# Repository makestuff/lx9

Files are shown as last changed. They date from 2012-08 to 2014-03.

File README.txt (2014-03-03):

COPYRIGHT & DISCLAIMER
----------------------

Copyright (C) 2014 MakeStuff (http://makestuff.eu)

This documentation describes Open Hardware and is licensed under the CERN Open
Hardware Licence v1.2. You may redistribute and modify this documentation under
the terms of the CERN OHL v1.2 (http://ohwr.org/cernohl). This documentation is
distributed WITHOUT ANY EXPRESS OR IMPLIED WARRANTY, INCLUDING OF
MERCHANTABILITY, SATISFACTORY QUALITY AND FITNESS FOR A PARTICULAR PURPOSE.
Please see the CERN OHL v1.2 for applicable conditions.

MAKESTUFF LX9 BOARD REV3
------------------------

Features:
   * 80mm x 80mm, 4-layer PCB (KiCad format).
   * Xilinx Spartan-6 LX9 FPGA[1].
   * Uses FPGALink[2] for programming & host communication.
   * Cypress FX2LP Hi-Speed USB interface (~45 MByte/s).
   * 46 FPGA I/Os on top edge-connector, well-grounded.
   * SPI-bus and 8 FX2LP I/Os on bottom edge-connector.
   * 16 MBytes of SDRAM.
   * SD-card slot.
   * 4 Mbit config flash (~40% free for application data).
   * Flexible power options.

It is intended to be small enough and cheap enough to be used as a building-
block for larger FPGA-based projects, and to be solderable at home with the bare
minimum of tools (i.e no reflow oven, just a decent soldering iron). The
component cost for a small (e.g 10-off) run comes to about $40 for each board,
including the PCB.

The design files are in KiCad format (http://www.kicad-pcb.org). I used this:

http://iut-tice.ujf-grenoble.fr/cao/old_versions/kicad-2012-01-19-BZR3256-stable-UBUNTU_10.10_full_with_components_doc.tgz

...running on x86_64 Ubuntu 12.04.

[1]http://www.xilinx.com/products/silicon-devices/fpga/spartan-6/lx.htm
[2]http://www.makestuff.eu/wordpress/software/fpgalink

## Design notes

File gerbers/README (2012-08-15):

The board is 80mm square, four layers of 1oz copper on FR4 TG130, regular green
soldermask on top & bottom, silkscreen on top & bottom, non-RoHS HASL surface.

There are four NPTH drills: two on CONN1 & two on CONN3; the rest are PTH.

PCB outline:
  lx9-PCB_Edges.gbr

Drills:
  lx9.drl (plated holes)
  lx9-NPTH.drl (non-plated holes)

Top layer:
  lx9-Front.gtl (copper)
  lx9-Mask_Front.gts (soldermask)
  lx9-SilkS_Front.gto (silkscreen)

Ground layer (nearest the top):
  lx9-GND.gbr

+3.3V layer (nearest the bottom):
  lx9-3.3V.gbr

Bottom layer:
  lx9-Back.gbl (copper)
  lx9-Mask_Back.gbs (soldermask)
  lx9-SilkS_Back.gbo (silkscreen)

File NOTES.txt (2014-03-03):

BILL OF MATERIALS
-----------------

Qty  Mfg        Part                   Site     Notes  Suggested Source
1    Xilinx     XC6SLX9-2TQG144C       U1       [1]
1    Cypress    CY7C68013A-56PVXC      U2       [2]
1    Micron     MT48LC8M16A2P-7E       U3       [3]
1    Microchip  24LC128-I/SN           U4              http://uk.rs-online.com/web/p/eeprom-memory-chips/6879089
1    Micron     M25P40-VMN6            U5              http://uk.rs-online.com/web/p/flash-memory-chips/7824597
1    HLWCONN    HW-SD-001-02           CONN1           http://www.ebay.com/itm/180794795415 [SU]
1    -          2x40-pin 2mm header    CONN2    [4]    http://www.ebay.com/itm/170648544414
1    -          Female Mini-B USB skt  CONN3           http://www.ebay.com/itm/251126968870
1    -          2x18-pin 2mm header    CONN4    [5]    http://www.ebay.com/itm/170842982073
1    -          24MHz HC-49/US XTAL    XTAL1           http://www.ebay.com/itm/261078491239
3    -          2.54mm 2-pin jumper    J1-3     [6]    http://www.ebay.com/itm/170902513437
1    -          2.54mm 3-pin jumper    J4       [6]                       "
5    -          22uF EIA3528 tant      C6,9-12  [7]    http://www.ebay.com/itm/160306954443
2    -          22pF 0805 capacitors   C13-14          http://www.ebay.com/itm/251019275826
25   -          470nF 0805 capacitors  *        [8]    http://www.ebay.com/itm/251025068518
4    -          10K 0805 resistors     R1-4,10
3    -          2.2K 0805 resistors    R5-6,9   [9]
1    -          0805 resistor          R11      [10]
2    -          0805 resistor          R7-8     [11]
1    -          0805 capacitor         C30      [11]
1    -          AMS1117 SOT-223 3.3V   REG3.3          http://www.ebay.com/itm/170845847551
1    -          AMS1117 SOT-223 1.2V   REG1.2          http://www.ebay.com/itm/170966438741

NOTES
-----

[1] You can also use an LX4 FPGA: XC6SLX4-2TQG144C

[2] A CY7C68014A-56PVXC will also work, as will the 8KiB CY7C68013-56PVXC, but
    it's not recommended; I can't guarantee the firmware will stay inside the
    8KiB limit forever.

[3] Any 64Mbit or 128Mbit SDRAM with the same organization/pinout will suffice.
    For example: Micron MT48LC8M16A2P-6A or MT48LC8M16A2P-7E,
                 Samsung K4S281632F-TC(L)-60 or K4S281632F-TC(L)-75
                 Alliance AS4C8M16S-6TCN or AS4C8M16S-7TCN
                 AMIC A43L3616AV-7F
                 ISSI IS42S16400 (64Mbit)

    You can also probably use a 256Mbit SDRAM like K4S561632N, but it has 13
    address pins, so you'll either have to install a 10K pull-down at R12 (thus
    only using the bottom half of each bank) or connect a flying wire from the
    R12 pad near the SDRAM to an available FPGA I/O. Use of a 256Mbit SDRAM is
    currently untested.

[4] An appropriate mating connector is http://www.ebay.com/itm/180611505374

[5] An appropriate mating connector is hard to find. You could cut from [2].

[6] You can cut 2-pin and 3-pin jumpers from a 40-pin single-row strip.

[7] The actual value and properties aren't too important; 10uF will do too.

[8] These are decoupling capacitors, so their values are not too important.
    They're located at C1-5,7-8,15-29,31.

[9] R5 & R6 are intended to pull up the SCL & SDA lines of the FX2's I2C bus.
    The FX2 will not start without them. R9 is a pull-down on M1. This ensures
    that the FPGA sees M[1:0] = "01", which is interpreted as "master serial".
    If your FPGA is refusing to boot, the first thing to check is that the M1
    side of R9 is less than 0.8V (the V[IL] maximum).
    Ref: Mode pins in Xilinx UG380 table 2.1.
    Ref: V[IL] maxumum in Xilinx DS162 table 9.

[10] This is a series resistor on FPGA pin 39 (INIT_B), which is an open-drain
     output during configuration. It will be driven low in the event of a CRC
     error during configuration. It's up to you to choose an appropriate value,
     and to design the external hardware connected to P39 appropriately.
     Ref: Xilinx UG380 table 2.2.

[11] The intent of R7-8 & C30 is to form a voltage-divider between the USB 5V
     supply and GND, and feed it to the FX2's WAKEUP input, thus allowing it to
     detect a USB disconnect when the board is in self-powered configuration.
     For example: http://pastebin.com/raw.php?i=L6LsEW8D

     At the moment, the FPGALink firmware will put the FX2 in suspend mode
     (stopping the FPGA's IFCLK) if this happens:
     https://github.com/makestuff/fx2lib/blob/master/fw/fw.c#L81

     You should probably leave R7-8 and C30 unpopulated unless you know what
     you're doing.

[SU] Seller Unverified. All other suggested sources are "tried and tested".
     Note that suggested sources are just that: suggestions.

POWER OPTIONS
-------------

There are three power jumpers which allow you to configure how your board is
powered.

J2: Make the LX9 board's 3.3V rail available on CONN2.
J3: Use the LX9 board's regulator to power the 3.3V rail.
J4: Select the 5V rail routing (USB, EXT, ALL, NIL)

J4   J3 J2 
NIL  N  N    -
USB  N  N    -
EXT  N  N    -
ALL  N  N    -

NIL  Y  N    FPGA powered by CONN2 3.3V
USB  Y  N    -
EXT  Y  N    -
ALL  Y  N    -

NIL  N  Y    -
USB  N  Y    FPGA powered by USB 5V via onboard 3.3V regulator
EXT  N  Y    FPGA powered by CONN2 5V via onboard 3.3V regulator
ALL  N  Y    FPGA powered by USB 5V via onboard 3.3V regulator; USB 5V also supplied to CONN2

NIL  Y  Y    -
USB  Y  Y    FPGA powered by USB 5V via onboard 3.3V regulator; regulator output also supplied to CONN2
EXT  Y  Y    FPGA powered by CONN2 5V via onboard 3.3V regulator; regulator output also supplied to CONN2
ALL  Y  Y    FPGA powered by USB 5V via onboard 3.3V regulator; regulator output and USB 5V also supplied to CONN2

Configurations marked "-" should not be used.

CONN2 NOTES
-----------

Most of the signals on CONN2 are general-purpose, but a couple of them have
special functions which must be honoured:

P144:
  This is HSWAPEN: it is pulled high by the FPGA during configuration,
  disabling the I/O pull-ups on most of the user I/O. Explicitly pulling it
  low enables the pull-ups on most user I/O (see Xilinx UG380 table 5.2 for
  exceptions).

P39:
  This is INIT_B: it is an open-drain output during configuration. It will be
  driven low in the event of a CRC error when booting from flash. There is a
  current-limiting series resistor R11 which is intended to protect the
  hardware in the event that the external hardware drives it high during
  configuration. R11's value is undefined in the BOM: you need to think about
  an appropriate value for your application.

+5V & +3.3V:
  These may be either power sources or power sinks. When designing external
  hardware to be connected to CONN2 you need to be very clear about this, and
  set the power jumpers appropriately.

GND:
  When designing external hardware, use all the available grounds.

FX2 EEPROM ISOLATION JUMPER
---------------------------

In the event that bad firmware is loaded into the FX2's EEPROM, it will be
necessary to isolate it by powering on the board with J1 open. The FX2 will
enumerate as the default device (04B4:8613). At that point you can short the
jumper again and load new firmware into the FX2's RAM, and use that to write
the EEPROM with good firmware (or clear it so the FX2 ignores it on power-on).

OPTIONAL COMPONENTS
-------------------

You can omit the SDRAM if you don't need it.

You can omit the SD-card slot if you don't need it.

You can omit the FX2's EEPROM and the FPGA's flash if you don't intend to ever
run the board standalone (i.e you intend for the board to be always connected
to a computer via USB and you don't mind loading FX2 firmware and
JTAG-programming the FPGA every time you power up the board). However, you must
not omit R5 & R6; these pull up the FX2's I2C bus; the FX2 will not enumerate
without them.

R12 may be left unpopulated if you used a 64Mbit or 128Mbit SDRAM.

SUPPORT TOOLS/HDL/SOFTWARE
--------------------------

The board is designed to be used with FPGALink (http://bit.ly/fpgalink), but of
course you're free to write your own HDL module, FX2 firmware and host-side
library to do JTAG-programming and slave-FIFO communication over USB if you
wish.

The first time you connect the board, it will enumerate as the default FX2
VID:PID of 04B4:8613. The first step is to use the "flcli" tool to program the
EEPROM so the FX2 boots the FPGALink firmware on startup:

  flcli -i 04b4:8613 -v 1d50:602b:0002 --eeprom=std

If you have more than one board and want to address them separately, just
increment the "0002" for subsequent boards.

Now you can program the FPGA over JTAG:

  flcli -v 1d50:602b:0002 -p J:A7A0A3A1:your-design.xsvf

If you want to permanently load a design into the FPGA's boot flash, you can do
so using the spi-talk design:

  cd makestuff/hdlmake/apps
  ../bin/hdlmake.py -g makestuff/spi-talk
  cd makestuff/spi-talk/vhdl
  ../../../../bin/hdlmake.py -t ../templates/fx2min/vhdl -b lx9r3 -p fpga
  flcli -v 1d50:602b:0002 -p J:A7A0A3A1:fpga.xsvf

You can now use the "gordon" tool to load the flash:

  gordon -v 1d50:602b:0002 -t indirect:1 -w your-design.bin:0

The board will subsequently boot into your design on power-up.

There are various HDL applications which may be of interest to you:

  https://github.com/makestuff/blinky
  https://github.com/makestuff/swled
  https://github.com/makestuff/readback
  https://github.com/makestuff/spi-talk
  https://github.com/makestuff/logic-sampler

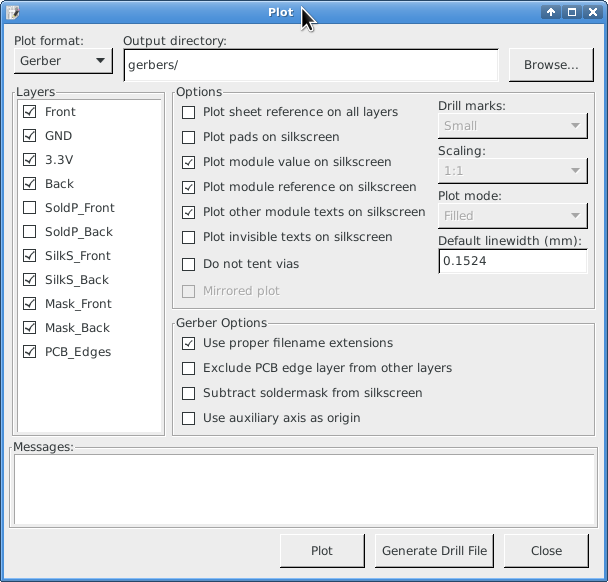
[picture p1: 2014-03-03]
gerbers/plotOpts.png

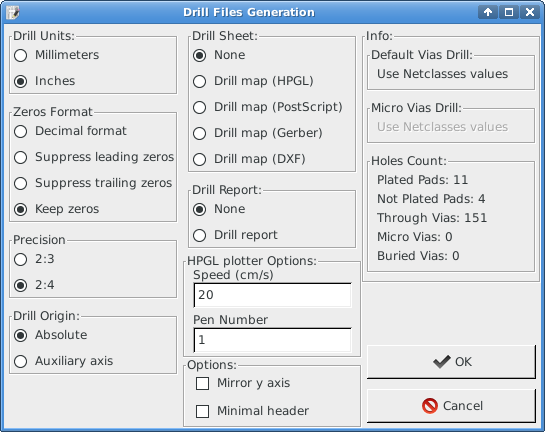
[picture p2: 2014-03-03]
gerbers/drillOpts.png

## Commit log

2012-08-15 Initial release
    [lx9.brd, lx9.sch]
2012-08-15 Final v1.0 silkscreen
    [lx9.brd, lx9.sch]
2012-08-15 Last netlist export; final v1.0 silkscreen
    [lx9.brd, lx9.sch]
2012-08-15 Ooops, left a value in
    [lx9.brd]
2012-08-15 Added slivers to prevent copper pour artifacts near FPGA
    [lx9.brd]
2012-08-16 Added makefile for gerber inspection and zip generation
2012-08-16 Changed copyright to match silkscreen
2013-05-24 Changes as a result of generating gerbers
    [lx9.brd]
2013-11-05 Removed mounting holes, fixed module mapping for J4
    [lx9.brd]
2013-11-05 Renamed USB schematic component MS-USB-B
    [lx9.sch]
2013-11-06 Swap to mini-USB connector
    [lx9.brd]
2013-11-06 Routed with wide EEPROM pads and mini-USB
    [lx9.brd, lx9.sch]
2013-11-06 Swapped fx2Addr lines, removed R1
    [lx9.brd, lx9.sch]
2013-11-06 Tidied up labels
    [lx9.brd]
2013-11-06 More label tidying
    [lx9.brd, lx9.sch]
2013-11-06 Added config-flash
    [lx9.brd, lx9.sch]
2013-11-06 Switched 1025->128
    [lx9.brd, lx9.sch]
2013-11-08 Finishing touches
    [lx9.brd, lx9.sch]
2013-11-08 Moved jumper labels and 1.2V boundary
    [lx9.brd]
2013-11-09 Named all signals, give test-points meaningful names, removed CMPCS test-point
    [lx9.brd, lx9.sch]
2013-11-09 Fixed ERC errors, fixed track-separation inconsistency around FX2, verified DRC passes
    [lx9.brd, lx9.sch]
2013-11-09 Fixed up copper fills
    [lx9.brd]
2013-11-10 Added source URL
    [lx9.brd]
2013-11-10 Archive link
    [lx9.brd]
2013-11-10 Moved Spartan-6 label to avoid via
    [lx9.brd]
2014-02-22 Moved spiData_out to pin 64, so FPGA boots correctly from flash
    [lx9.brd, lx9.sch]
2014-03-03 Add NOTES.txt; use separate git label, enabling doc updates
    [lx9.brd, lx9.sch]
2014-03-03 Added missing .tar.gz to source URL
    [lx9.brd]
2014-03-03 Removed .tar.gz from checkin hash
    [lx9.brd]
2014-03-03 Added plot & drill screenshots & fixed target zip name in gerbers/Makefile
    [lx9.brd]
2014-03-03 Also subst gerbers/Makefile
